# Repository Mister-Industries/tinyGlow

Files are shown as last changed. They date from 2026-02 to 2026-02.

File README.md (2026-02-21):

# tinyGlow — Smart LED HAT for tinyCore ESP32-S3

<div align="center">





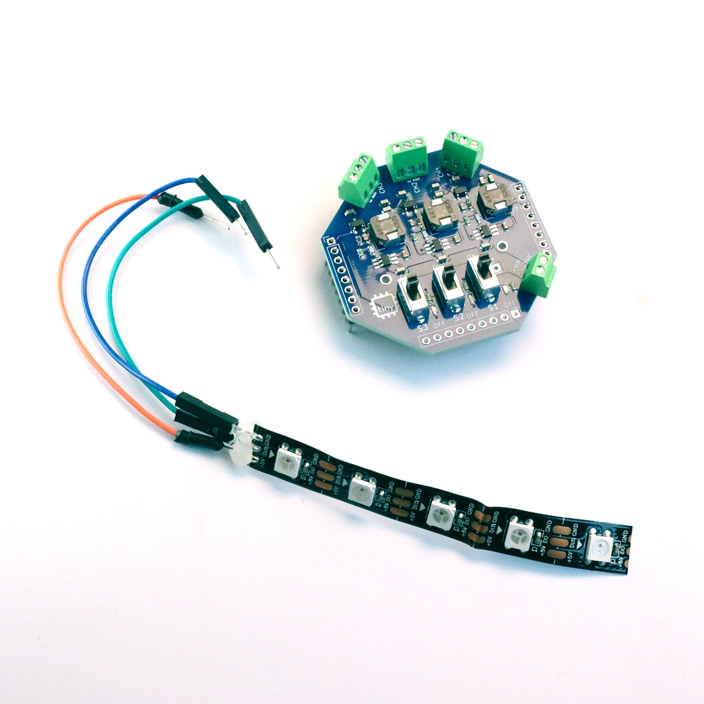
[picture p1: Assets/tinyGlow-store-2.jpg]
tinyGlow Projects


**A smart LED control HAT for the [tinyCore](https://github.com/Mister-Industries/tinyCore) ESP32-S3 platform.**

[Purchase](https://tinycore.cc/store/products/tinyGlow) · [Discord](https://discord.gg/hvJZhwfQsF) · [Documentation](https://docs.mr.industries)

</div>

---

### How to open the Schematic (KiCAD)
Screenshot of tinyGlow KiCAD Schematic
The tinyGlow design files are provided as a KiCAD project. KiCAD is a free, open-source PCB design tool.

To open the files:
1. Download and install [KiCAD](https://www.kicad.org/download/) (version 7.0 or later recommended).
2. Open KiCAD and click **File > Open Project** (or press Ctrl+O).
3. Navigate to the Hardware folder of this repository and select the `.kicad_pro` project file.
4. Once the project opens, you can access:
   - **Schematic Editor** - Double-click the `.kicad_sch` file to view the circuit design
   - **PCB Editor** - Double-click the `.kicad_pcb` file to view the board layout

The project will open with all associated files (schematic, PCB, and libraries) ready to view and edit.

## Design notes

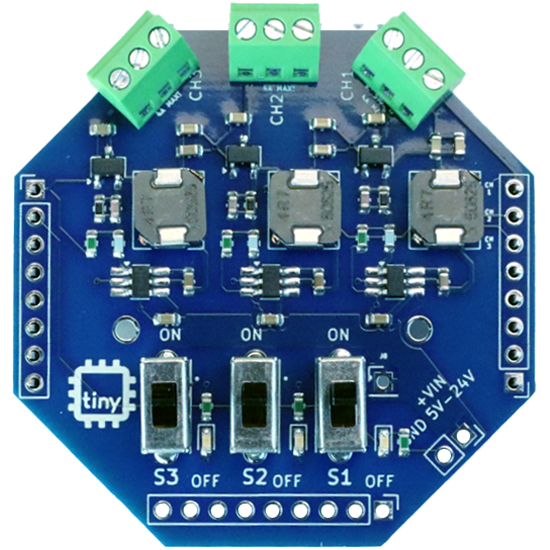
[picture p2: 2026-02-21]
Assets/tinyGlow.png

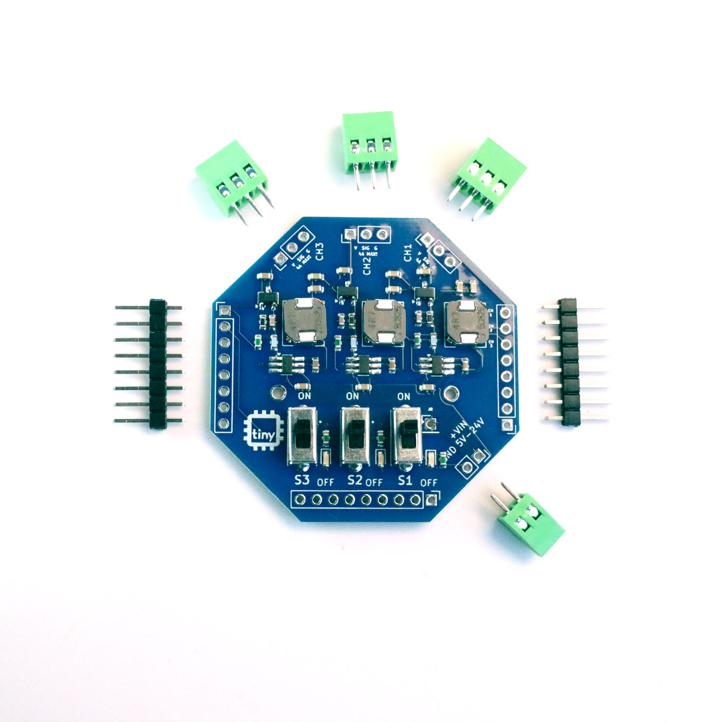
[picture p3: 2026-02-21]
Assets/tinyGlow-store-1.jpg

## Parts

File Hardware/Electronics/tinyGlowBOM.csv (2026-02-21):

Reference | Value | Datasheet | Footprint | Qty | DNP
C1,C2,C7,C8,C9,C10,C11,C12,C13,C17,C20,C21 | 22uF | ~ | Capacitor_SMD:C_0603_1608Metric | 12
C3,C4,C18 | .1uF | ~ | Capacitor_SMD:C_0603_1608Metric | 3
C5,C6,C19 | 47pF | ~ | Capacitor_SMD:C_0603_1608Metric | 3
D1,D2,D3 | LED | ~ | Diode_SMD:D_0603_1608Metric | 3
IC1,IC2,IC3 | RT6255BHGJ6F |  | Package_TO_SOT_SMD:TSOT-23-6_HandSoldering | 3
IC4,IC5,IC6 | LS0504EVT233 | https://www.mouser.in/datasheet/2/240/Littelfuse-3045601.pdf | Package_TO_SOT_SMD:TSOT-23 | 3
L1,L2,L3 | 4.7uH | ~ | LibrarySPM6530T:SPM6530T-4R7M | 3
R1,R2,R7 | 5K | ~ | Resistor_SMD:R_0603_1608Metric | 3
R3,R4,R8 | 147K | ~ | Resistor_SMD:R_0603_1608Metric | 3
R5,R6,R9 | 20K | ~ | Resistor_SMD:R_0603_1608Metric | 3
R10,R11,R12 | 220 | ~ | Resistor_SMD:R_0603_1608Metric | 3
S1,S2,S3 | OS102011MS2QN1 | https://www.ckswitches.com/media/1428/os.pdf | logos.preety:OS102011MA1QN1 | 3

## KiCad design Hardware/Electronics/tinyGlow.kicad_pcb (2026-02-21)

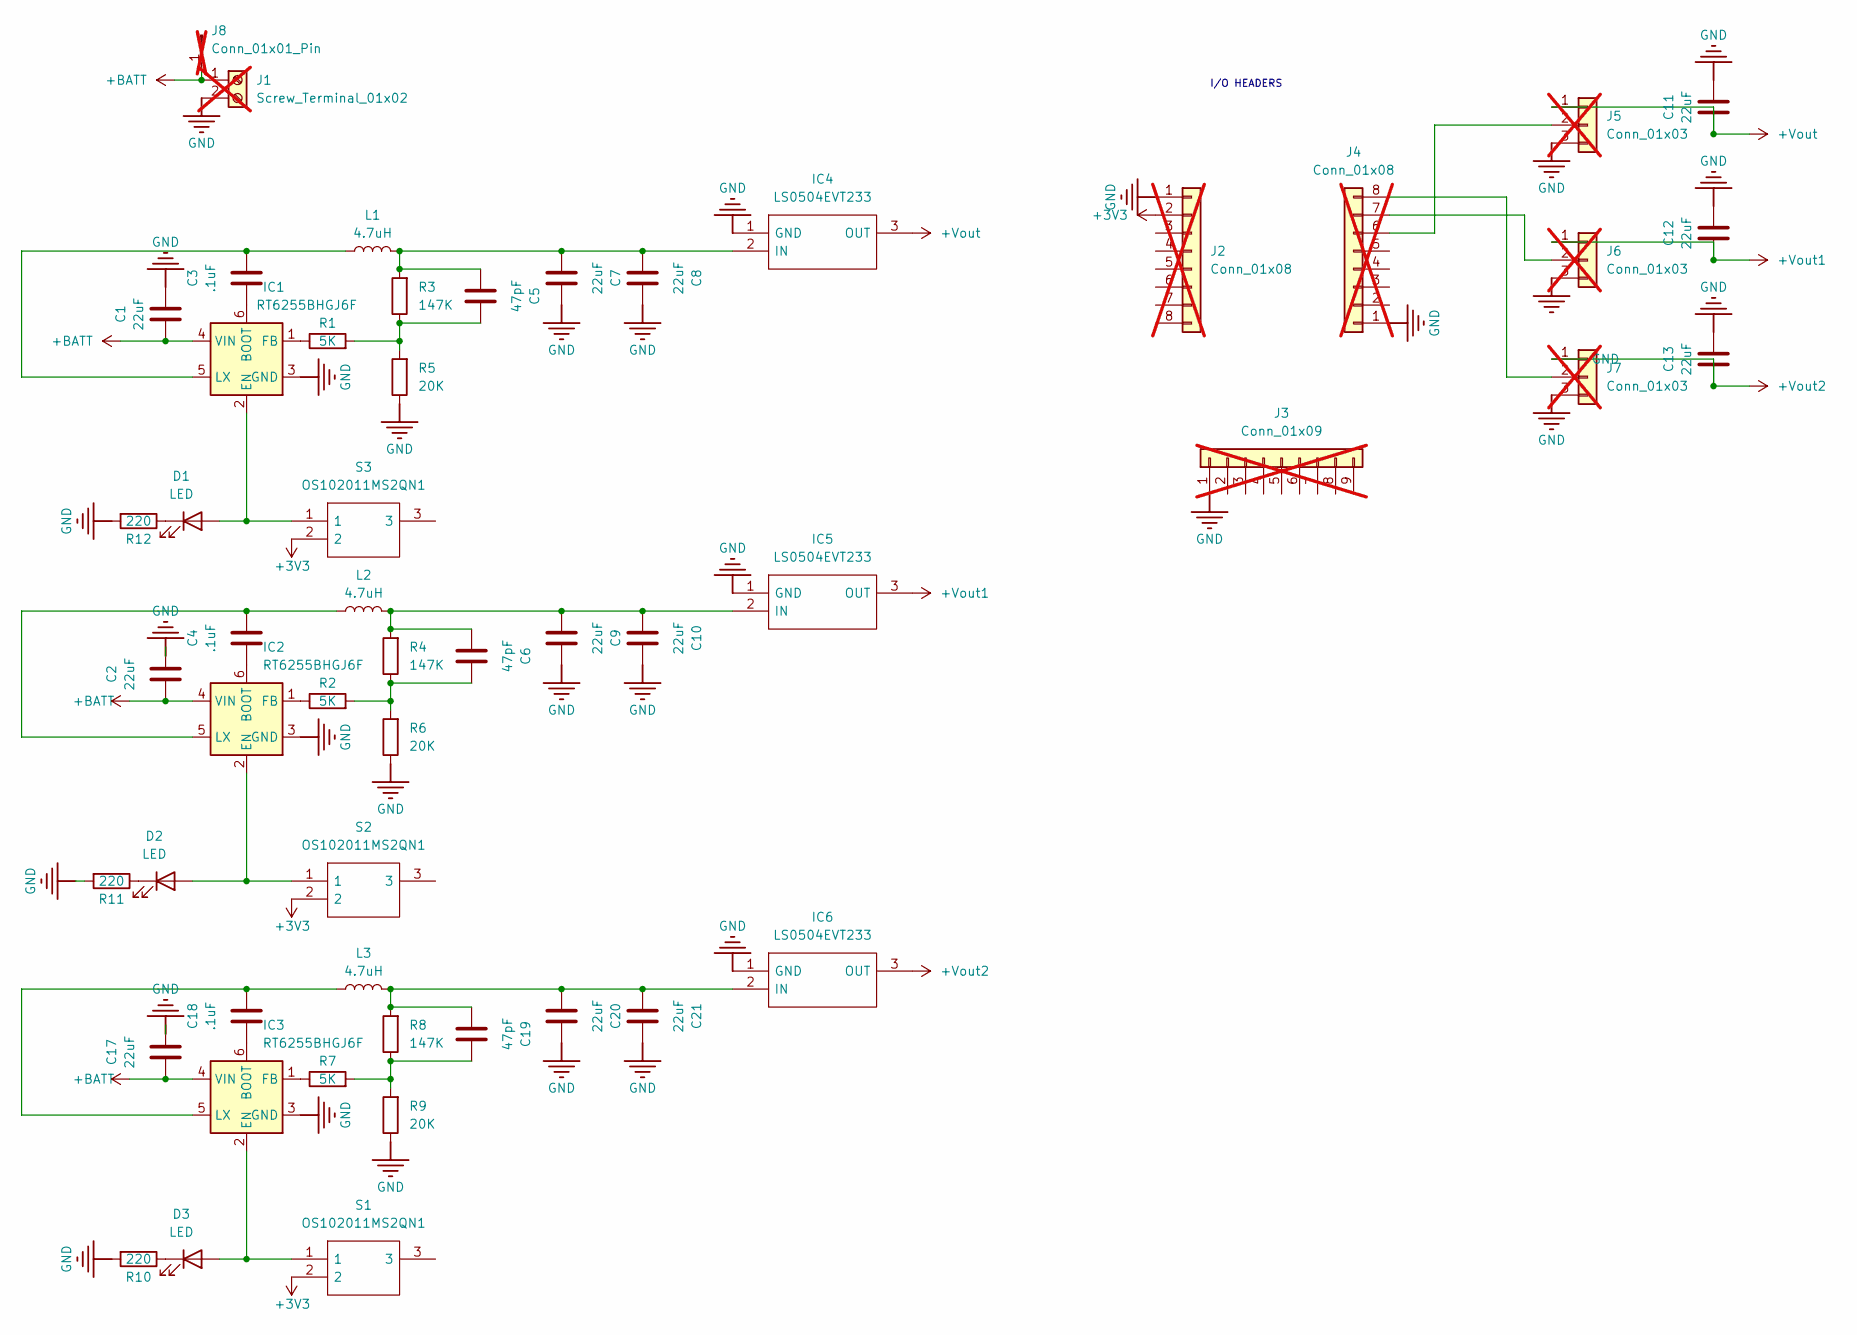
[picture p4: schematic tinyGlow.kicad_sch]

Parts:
C1, C2, C7, C8, C9, C10, C11, C12, C13, C17, C20, C21: 22uF; C_0603_1608Metric
C3, C4, C18: .1uF; C_0603_1608Metric
C5, C6, C19: 47pF; C_0603_1608Metric
D1, D2, D3: LED; D_0603_1608Metric
IC1, IC2, IC3: RT6255BHGJ6F; TSOT-23-6_HandSoldering
IC4, IC5, IC6: LS0504EVT233; TSOT-23; Mouser Part Number 576-LS0504EVT233
J1: Screw_Terminal_01x02; PinSocket_1x02_P2.54mm_Vertical; not fitted
J2, J4: Conn_01x08; PinHeader_1x08_P2.54mm_Vertical; not fitted
J3: Conn_01x09; PinHeader_1x09_P2.54mm_Vertical; not fitted
J5, J6, J7: Conn_01x03; PinHeader_1x03_P2.54mm_Vertical; not fitted
J8: Conn_01x01_Pin; PinHeader_1x01_P2.54mm_Vertical; not fitted
L1, L2, L3: 4.7uH; SPM6530T-4R7M
R1, R2, R7: 5K; R_0603_1608Metric
R3, R4, R8: 147K; R_0603_1608Metric
R5, R6, R9: 20K; R_0603_1608Metric
R10, R11, R12: 220; R_0603_1608Metric
S1, S2, S3: OS102011MS2QN1; OS102011MA1QN1; Mouser Part Number 611-OS102011MS2QN1

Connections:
+3V3: J2.2, S1.2, S2.2, S3.2
+BATT: C1.2, C2.1, C17.1, IC1.4 (VIN), IC2.4 (VIN), IC3.4 (VIN), J1.1, J8.1
+Vout: C11.2, IC4.3 (OUT), J5.1
+Vout1: C12.2, IC5.3 (OUT), J6.1
+Vout2: C13.2, IC6.3 (OUT), J7.1
GND: C1.1, C2.2, C7.2, C8.2, C9.2, C10.2, C11.1, C12.1, C13.1, C17.2, C20.2, C21.2, IC1.3 (GND), IC2.3 (GND), IC3.3 (GND), IC4.1 (GND), IC5.1 (GND), IC6.1 (GND), J1.2, J2.1, J3.1, J4.1, J5.3, J6.3, J7.3, R5.1, R6.1, R9.1, R10.2, R11.2, R12.2
unnamed: C5.2, R1.2, R3.1, R5.2
unnamed: C6.2, R2.2, R4.1, R6.2
unnamed: C19.2, R7.2, R8.1, R9.2
unnamed: D1.2 (A), IC1.2 (EN), S3.1
unnamed: D1.1 (K), R12.1
unnamed: D2.2 (A), IC2.2 (EN), S2.1
unnamed: D2.1 (K), R11.1
unnamed: D3.2 (A), IC3.2 (EN), S1.1
unnamed: D3.1 (K), R10.1
unnamed: C3.1, IC1.6 (BOOT)
unnamed: IC1.1 (FB), R1.1
unnamed: C3.2, IC1.5 (LX), L1.1
unnamed: C4.1, IC2.6 (BOOT)
unnamed: IC2.1 (FB), R2.1
unnamed: C4.2, IC2.5 (LX), L2.1
unnamed: C18.1, IC3.6 (BOOT)
unnamed: IC3.1 (FB), R7.1
unnamed: C18.2, IC3.5 (LX), L3.1
unnamed: C5.1, C7.1, C8.1, IC4.2 (IN), L1.2, R3.2
unnamed: C6.1, C9.1, C10.1, IC5.2 (IN), L2.2, R4.2
unnamed: C19.1, C20.1, C21.1, IC6.2 (IN), L3.2, R8.2
unnamed: J4.6, J5.2
unnamed: J4.7, J6.2
unnamed: J4.8, J7.2

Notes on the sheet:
I/O HEADERS

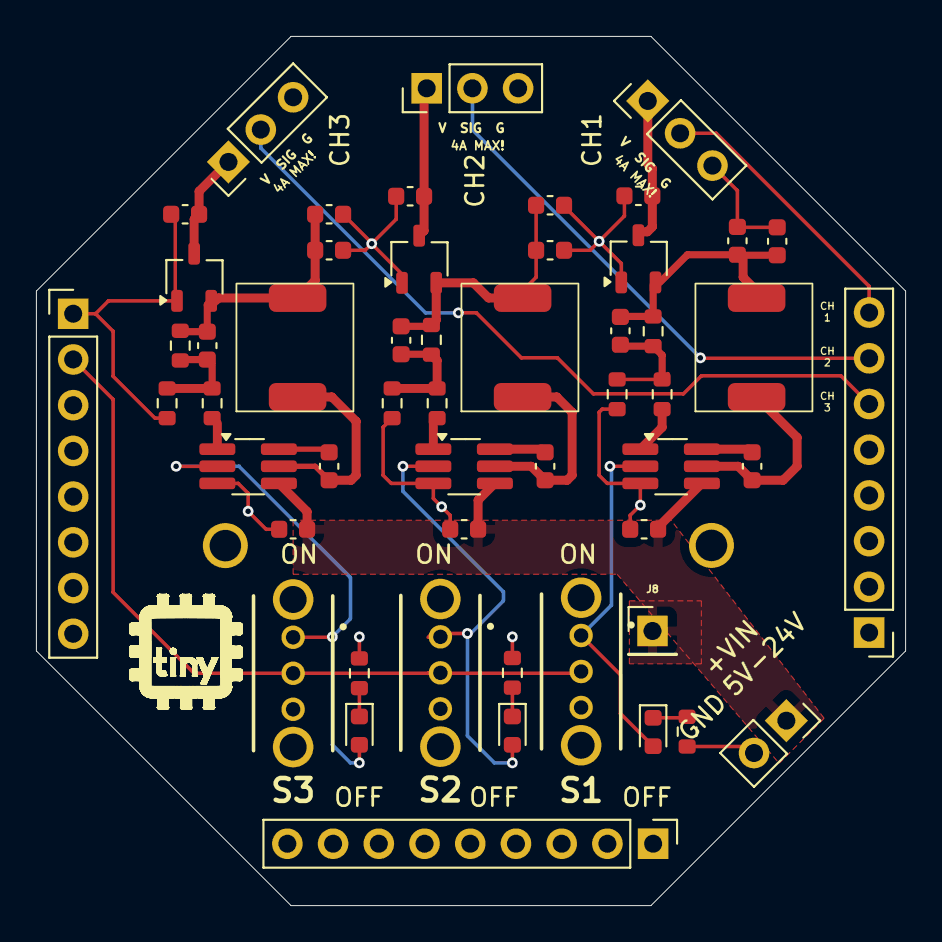
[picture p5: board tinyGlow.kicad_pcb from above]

Board: 2 copper layers, 48.3 x 48.3 mm, 53 parts (0 on the bottom side), 30 nets.

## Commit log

2026-02-21 Adds photos and KiCAD schematics
    [tinyGlow.kicad_pcb, tinyGlow.kicad_sch, tinyGlowBOM.csv]
2026-02-21 Revise README with KiCAD details
    Updated project description and added installation instructions for KiCAD.
2026-02-21 Updated tinyGlow Schematics
    [tinyGlow.kicad_pcb]

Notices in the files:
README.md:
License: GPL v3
